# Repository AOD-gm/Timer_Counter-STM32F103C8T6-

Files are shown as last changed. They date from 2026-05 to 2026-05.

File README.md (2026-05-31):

# TIMER COUNTER
<p align="left">
  
  
  
</p>

---
### 📂 Chi tiết thư mục

<details>
<summary><b>📂 Bấm để xem cấu trúc thư mục dự án (Project Structure)</b></summary>

```text
📂 Timer Counter
├── 📦 Core
│   ├── 📂 Inc
│   │   ├── 📜 DS1307.h        # Thư viện RTC DS3231/DS1307
│   │   ├── 📜 Esp_01.h        # Thư viện giao tiếp ESP-01
│   │   ├── 📜 FontSSD1306.h   # Font chữ cho OLED SSD1306
│   │   ├── 📜 HLK_LD2410.h    # Driver cảm biến Radar hiện diện
│   │   ├── 📜 Keypad.h        # Thư viện ma trận phím
│   │   ├── 📜 Menu_UI.h       # Logic Menu & Giao diện OLED
│   │   ├── 📜 MH-R38.h        # Giải mã tín hiệu Remote IR
│   │   └── 📜 SSD1306.h       # Thư viện điều khiển màn hình OLED
│   └── 📂 Src
│       ├── 📜 main.c          # Luồng xử lý chính
│       ├── 📜 Menu_UI.c       # Cấu trúc hiển thị Menu
│       └── 📜 ...             # Các file xử lý tương ứng (.c)
├── 📦 Esp-01
│   ├── 📂 inc
│   │   └── 📜 wifiConfig.h    # Cấu hình WiFi & Web Server
│   └── 📂 src
│       └── 📜 WifiConfig.cpp  # Xử lý logic kết nối
└── 📦 PCB
    ├── 📂 GiaCong             # File Gerber, BOM để đặt mạch
    └── 📂 Timer_Counter       # File thiết kế gốc (KiCad)
 ```
 </details>

### 🛠️ Phần cứng sử dụng

**1. Vi điều khiển trung tâm**
* STM32F103C8T6 (ARM Cortex-M3)

**2. Cảm biến & Module ngoại vi**
* **Mô-đun kết nối:** ESP8266 (ESP-01) cấu hình Web Server.
* **Cảm biến hiện diện:** Radar HLK-LD2410C (nhận diện vi chuyển động).
* **Module thời gian thực:** DS3231 / DS1307 (lưu giữ ngày giờ).
* **Màn hình hiển thị:** OLED 0.96 inch (IC SSD1306).

* **Khối điều khiển & Giao tiếp:** Bàn phím ma trận (Keypad) & MH-R38 (nhận tín hiệu Remote IR)

## Sơ đồ nối chân 
| 🛠️ Phần cứng | 📌 Chân STM32 | 🔗 Giao tiếp | 📝 Chức năng |
| :--- | :---: | :---: | :--- |
| 🖥️ **OLED SSD1306** | `PB6 (SCL)`<br>`PB7 (SDA)` | `I2C1` | Hiển thị thông tin giao diện người dùng |
| 🌐 **ESP-01 (WiFi)** | `PA9 (TX)`<br>`PA10 (RX)` | `UART1` | Web Server & Phát WiFi điều khiển từ xa |
| ⏳ **RTC DS3231** | `PB6 (SCL)`<br>`PB7 (SDA)` | `I2C1` | Lưu thời gian & Báo thức (chạy khi mất điện) |
| 📡 **Radar LD2410** | `PA2 (TX)`<br>`PA3 (RX)` | `UART2` | Nhận diện người (vi chuyển động) |
| 🎛️ **Keypad 4x4** | `PB12-15`<br>`PA4-7` | `GPIO` | Điều khiển Menu |
| 🖲️ **Mắt thu IR** | `PA1` | `TIM2` | Nhận tín hiệu Remote hồng ngoại

## Yêu Cầu
<p align="center">
  
  
  
  
  
  
  
  <br/><br/>

<p align="center">
  
  
  
  
</p>

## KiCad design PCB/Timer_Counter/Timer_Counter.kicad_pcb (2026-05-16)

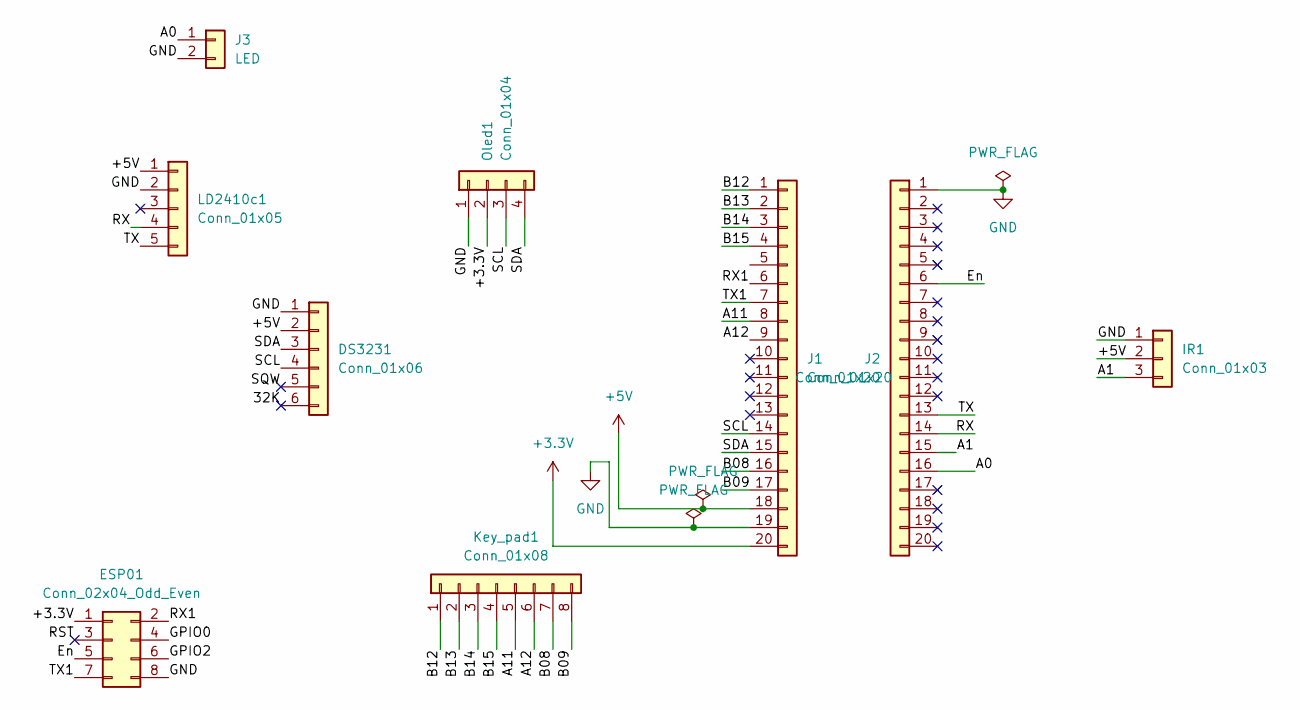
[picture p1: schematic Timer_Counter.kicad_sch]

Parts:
DS3231: Conn_01x06; PinSocket_1x06_P2.54mm_Vertical
ESP01: Conn_02x04_Odd_Even; PinSocket_2x04_P2.54mm_Vertical
IR1: Conn_01x03; PinSocket_1x03_P2.54mm_Vertical
J1, J2: Conn_01x20; PinSocket_1x20_P2.54mm_Vertical
J3: LED; PinSocket_1x02_P2.00mm_Vertical
Key_pad1: Conn_01x08; PinHeader_1x08_P2.54mm_Vertical
LD2410c1: Conn_01x05; PinSocket_1x05_P2.54mm_Horizontal
Oled1: Conn_01x04; PinSocket_1x04_P2.54mm_Horizontal

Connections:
+3.3V: ESP01.1, J1.20, Oled1.2
+5V: DS3231.2, IR1.2, J1.18, LD2410c1.1
/32K: DS3231.6
/A0: J2.16, J3.1
/A1: IR1.3, J2.15
/A11: J1.8, Key_pad1.5
/A12: J1.9, Key_pad1.6
/B08: J1.16, Key_pad1.7
/B09: J1.17, Key_pad1.8
/B12: J1.1, Key_pad1.1
/B13: J1.2, Key_pad1.2
/B14: J1.3, Key_pad1.3
/B15: J1.4, Key_pad1.4
/En: ESP01.5, J2.6
/GPIO0: ESP01.4
/GPIO2: ESP01.6
/RST: ESP01.3
/RX: J2.14, LD2410c1.4
/RX1: ESP01.2, J1.6
/SCL: DS3231.4, J1.14, Oled1.3
/SDA: DS3231.3, J1.15, Oled1.4
/SQW: DS3231.5
/TX: J2.13, LD2410c1.5
/TX1: ESP01.7, J1.7
GND: DS3231.1, ESP01.8, IR1.1, J1.19, J2.1, J3.2, LD2410c1.2, Oled1.1

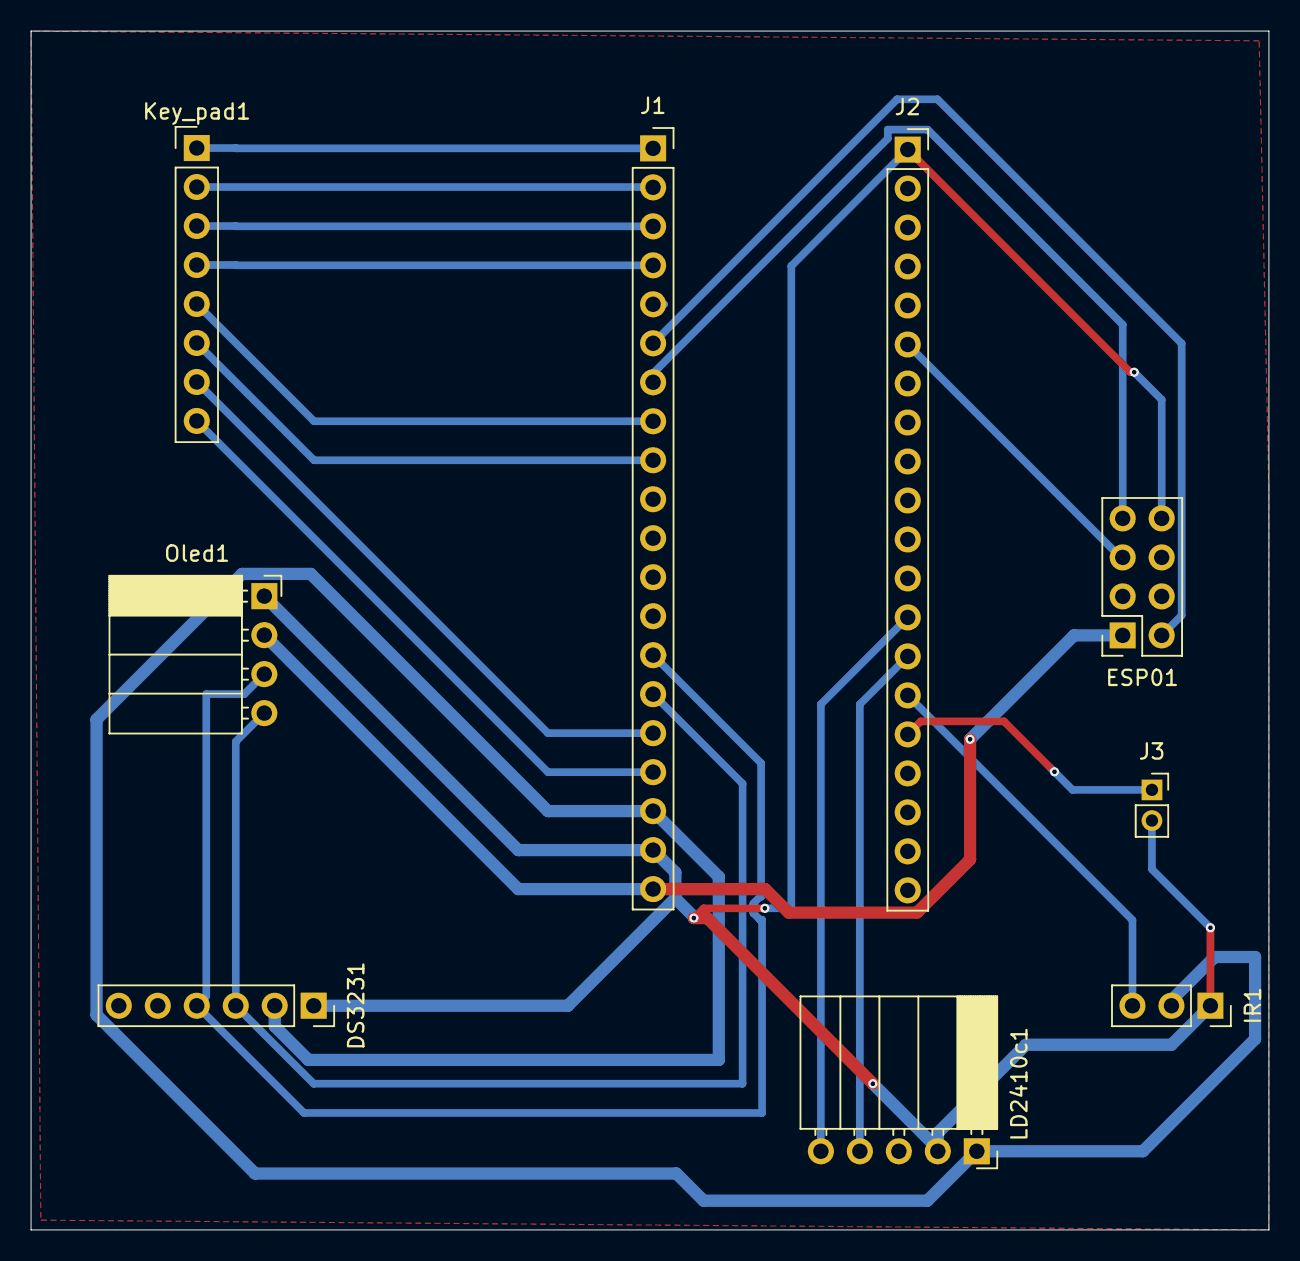
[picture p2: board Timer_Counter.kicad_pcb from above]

Board: 2 copper layers, 80.6 x 78.1 mm, 9 parts (0 on the bottom side), 20 nets.

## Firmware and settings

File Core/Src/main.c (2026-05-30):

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
/* Includes ------------------------------------------------------------------*/
#include "main.h"

/* USER CODE BEGIN Includes */
#include "DS3231.h"
#include "Keypad.h"
#include "SSD1306.h"
#include "FontSSD1306.h"
#include "MH-R38.h"
#include "Menu_UI.h"
#include "HLK_LD2410.h"
#include "Esp_01.h"
/* USER CODE END Includes */

I2C_HandleTypeDef hi2c1;

TIM_HandleTypeDef htim2;

UART_HandleTypeDef huart1;
UART_HandleTypeDef huart2;

/* USER CODE BEGIN PV */
extern uint8_t rx_byte;
/* USER CODE END PV */

void SystemClock_Config(void);
static void MX_GPIO_Init(void);
static void MX_I2C1_Init(void);
static void MX_TIM2_Init(void);
static void MX_USART2_UART_Init(void);
static void MX_USART1_UART_Init(void);
/**
  * @brief  The application entry point.
  * @retval int
  */
int main(void)
{

  /* MCU Configuration--------------------------------------------------------*/

  /* Reset of all peripherals, Initializes the Flash interface and the Systick. */
  HAL_Init();

  /* Configure the system clock */
  SystemClock_Config();

  /* Initialize all configured peripherals */
  MX_GPIO_Init();
  MX_I2C1_Init();
  MX_TIM2_Init();
  MX_USART2_UART_Init();
  MX_USART1_UART_Init();
  /* USER CODE BEGIN 2 */
  OLED_Init();
  OLED_Clear();
  DS3231_Init();
	IR_Init(&htim2);
	HLK_LD2410_Init(&huart2);
  HAL_UART_Receive_IT(&huart1, &rx_byte, 1);

  /* USER CODE END 2 */

  /* Infinite loop */
  /* USER CODE BEGIN WHILE */
  while (1)
  {
    /* USER CODE END WHILE */

    /* USER CODE BEGIN 3 */
		
		char key_pad=Keypad_Read();
		uint32_t key_ir = Read_RM();
    UI_ESP_Process();
    UI_System_Process();
		UI_Proccess_Keypad(key_pad);
		UI_Proccess_IR(key_ir);
		UI_Render();
		HAL_Delay(50);
	}
  /* USER CODE END 3 */
}

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
/* USER CODE BEGIN 4 */
void HAL_UART_RxCpltCallback(UART_HandleTypeDef *huart) {
    LD2410_UART_Callback(huart);
		ESP01_UART_Callback(huart);
}

/* USER CODE END 4 */
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


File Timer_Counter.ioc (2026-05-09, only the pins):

Mcu.UserName=STM32F103C8Tx
PA0-WKUP.Signal=GPIO_Output
PA1.Signal=S_TIM2_CH2
PA10.Signal=USART1_RX
PA11.Signal=GPIO_Input
PA12.Signal=GPIO_Input
PA13.Signal=SYS_JTMS-SWDIO
PA14.Signal=SYS_JTCK-SWCLK
PA15.Signal=GPIO_Input
PA2.Signal=USART2_TX
PA3.Signal=USART2_RX
PA8.Signal=GPIO_Input
PA9.Signal=USART1_TX
PB10.Signal=GPIO_Output
PB12.Signal=GPIO_Output
PB13.Signal=GPIO_Output
PB14.Signal=GPIO_Output
PB15.Signal=GPIO_Output
PB6.Signal=I2C1_SCL
PB7.Signal=I2C1_SDA
PB8.Signal=GPIO_Input
PB9.Signal=GPIO_Input
PC13-TAMPER-RTC.Signal=GPIO_Output
PD0-OSC_IN.Signal=RCC_OSC_IN
PD1-OSC_OUT.Signal=RCC_OSC_OUT

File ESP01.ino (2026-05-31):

#include <ESP8266WiFi.h>
#include <WiFiManager.h>
#include <PubSubClient.h>
const char* mqtt_server = "";
const char* device_id   = ""; 
const char* mqtt_user   = "";
const char* mqtt_pass   = ""; 

WiFiClientSecure espClient;
PubSubClient client(espClient);

void callback(char* topic, byte* payload, unsigned int length) {
  String message = "";
  for (int i = 0; i < length; i++) {
    message += (char)payload[i];
  }
  Serial.println(message);
}

void reconnect() {
  while (!client.connected()) {
    if (client.connect(device_id, mqtt_user, mqtt_pass)) {
      String topic = String("devices/") + String(device_id) + String("/messages/devicebound/#");
      client.subscribe(topic.c_str());
    } else {
      delay(5000);
    }
  }
}

void setup() {
  Serial.begin(115200);
  
  WiFiManager wifiManager;
  wifiManager.autoConnect("Setup");

  espClient.setInsecure(); 
  client.setServer(mqtt_server, 8883);
  client.setCallback(callback);
}

void loop() {
  if (!client.connected()) {
    reconnect();
  }
  client.loop();
}

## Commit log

2026-04-26 Xong hen gio bat tat led va ma hinh tren oled
2026-04-27 Tach file de nhin va them thu vien IR
2026-04-28 chinh sua file rac, them Menu_UI de quan ly oled va them kich thuoc 11x18 oled
2026-05-01 thêm thư viện HLK_LD2410C
2026-05-01 Thêm file pcb
    [Timer_Counter.kicad_pcb, Timer_Counter.kicad_sch]
2026-05-01 Thêm vài chức năng SSD1306
2026-05-03 Them pcb mơi sửa vào
    [Timer_Counter.kicad_pcb, Timer_Counter.kicad_sch]
2026-05-04 Them System Proccess để xử lý thiết bị ngoài
2026-05-08 Sửa lại vài thứ
2026-05-09 Xong mọi thứ
2026-05-09 Cập nhật file PCB
    [Timer_Counter-B_Cu.gbr, Timer_Counter-B_Mask.gbr, Timer_Counter-B_Paste.gbr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]
2026-05-09 Sửa IR
2026-05-09 Fix formatting in README.md for Timer_Counter section
2026-05-16 Cap nhat file thiet ke PCB
    [Timer_Counter-B_Cu.gbr, Timer_Counter-B_Mask.gbr, Timer_Counter-B_Paste.gbr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]
2026-05-19 Fix alarm and radar logic for ESP01
    [Menu_UI.c, main.c]
2026-05-19 Da fix xong loi bao thuc ESP01 va LED
    [MH-R38.c, Menu_UI.c, main.c]
2026-05-19 siêu cấp ĩ bug alarm :(((
    [Menu_UI.c]
2026-05-19 fix vài lỗi
2026-05-30 fix year register on DS3231 but not sucess :((
    [DS3231.c, Esp_01.c, Menu_UI.c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]
2026-05-30 add mode on web to easy ajust(saving mode can cause a problem because it unable esp01 so you can not remote after this
    [Menu_UI.c]

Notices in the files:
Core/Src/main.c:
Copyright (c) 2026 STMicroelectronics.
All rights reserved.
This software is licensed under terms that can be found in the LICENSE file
